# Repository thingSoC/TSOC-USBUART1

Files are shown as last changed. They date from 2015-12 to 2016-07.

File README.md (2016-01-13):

# TSOC-USBUART1

**TSOC-USBUART1** is a USB to UART Base Board **thingSoC Reference Design.** 

**thingSoC Reference Designs** are example thingSoC implementations that implement
various reference and testing circuits for demonstrating the use of the thingSoC libraries.
These reference designs can serve as starting templates for user designs.

**TSOC-USBUART1** includes a single channel USB to Serial(UART) interface, 
and status LED's, as well as an "FTDI" pinout compatible connector.

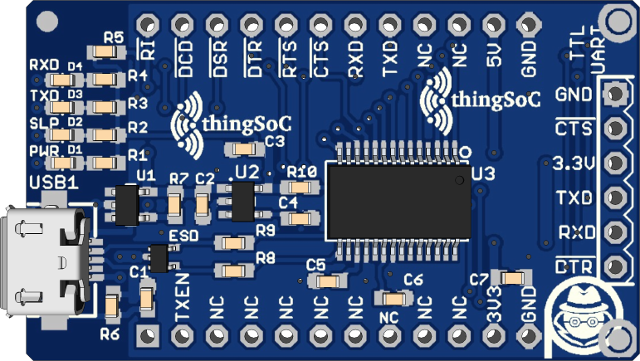
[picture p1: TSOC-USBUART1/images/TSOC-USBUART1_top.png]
thingSoC TSOC-USBUART1
[ 
*TSOC-USBUART1*](https://github.com/thingSoC/TSOC-USBUART1)

---------------------------------------

## TSOC-USBUART1 Status <a name="TSOC-USBUART1_status"/>

**01/13/2016:** 
Revision 3.1 - Revised USB ESD circuit to PA Standard USB2.0

**01/13/2016:** 
Revision 3.0 - NUF2221 ESD package pinout - PCB jumper with discrete resistors
Tested at 9600, 115200, 256000, 921600, 1843200 Baud rates

---------------------------------------

## TSOC-USBUART1 Documentation Index <a name="TSOC-USBUART1_documentation_index"/>

[TSOC-USBUART1 Project](http://thingsoc.github.io/projects/TSOC-USBUART1.html)

[TSOC-USBUART1 Hardware](https://github.com/thingSoC/TSOC-USBUART1/tree/master/TSOC-USBUART1/hardware)

---------------------------------------

## thingSoC Documentation Index <a name="thingSoC_documentation_index"/>

[thingSoC Organization Website](http://thingSoC.github.io)

[thingSoC FAQ - Frequently Asked Questions](http://thingsoc.github.io/support/faq.html)

---------------------------------------

[thingSoC 
*thingSoC*](http://thingsoc.github.io)

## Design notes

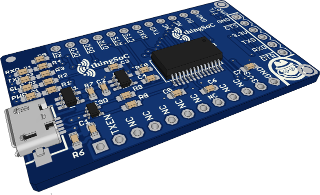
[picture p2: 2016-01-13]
TSOC-USBUART1/images/TSOC-USBUART1_model.png

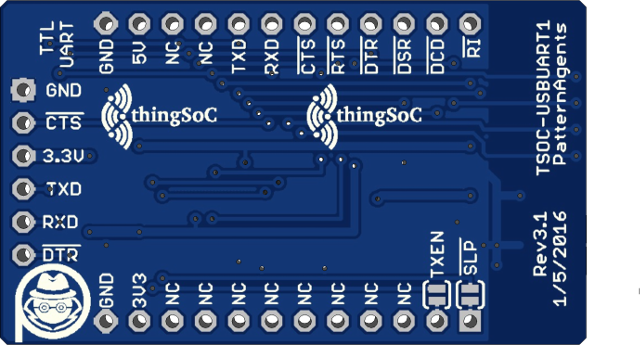
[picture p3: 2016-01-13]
TSOC-USBUART1/images/TSOC-USBUART1_bot.png

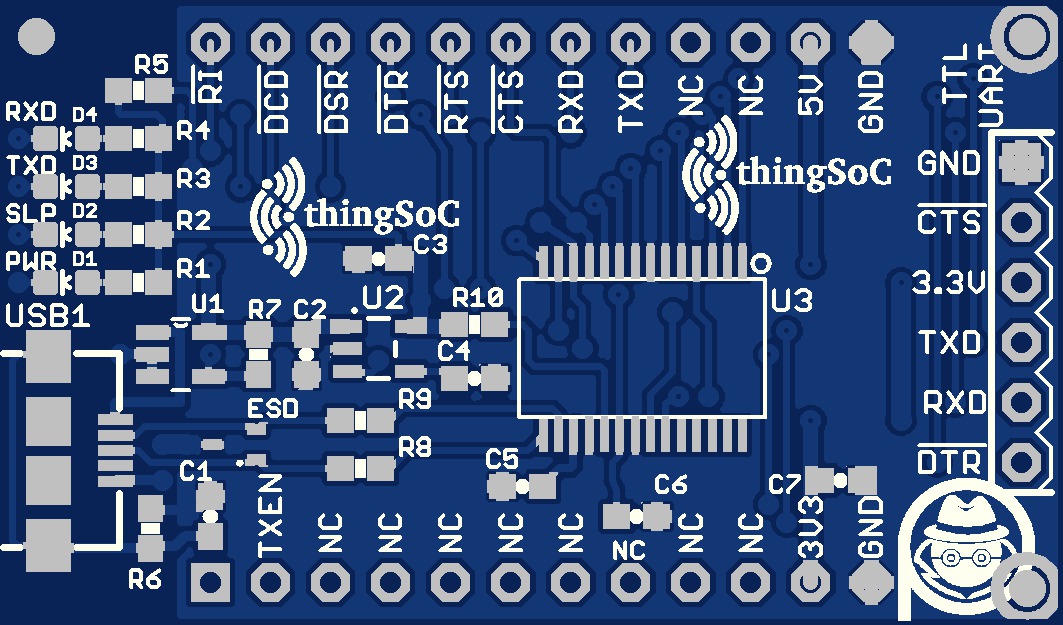
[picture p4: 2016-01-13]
TSOC-USBUART1/eagleUp/eagleUp_TSOC-USBUART1_board_top.jpg

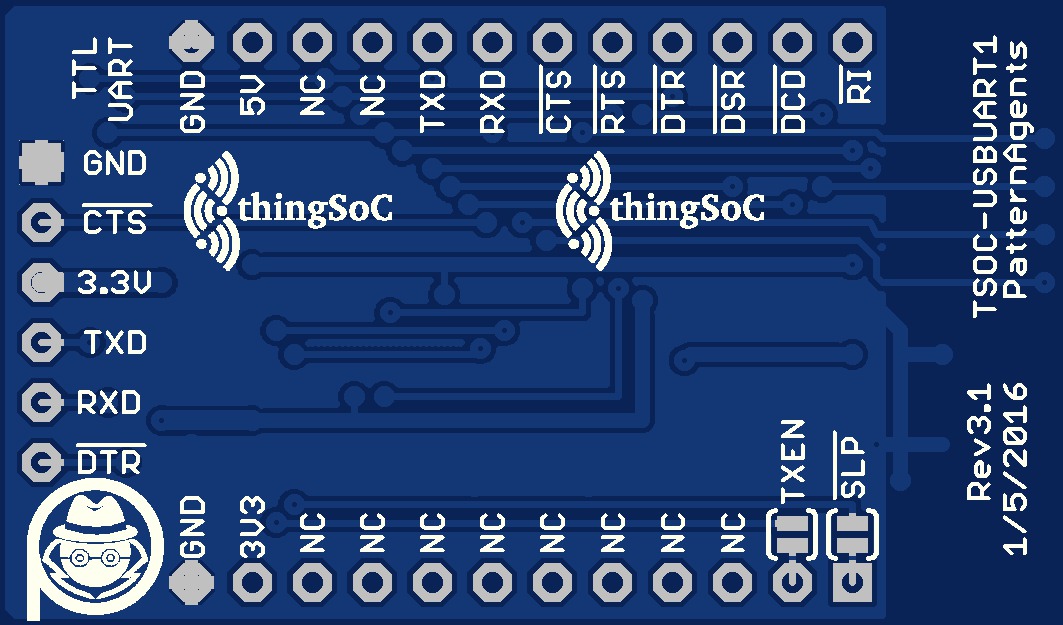
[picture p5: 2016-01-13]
TSOC-USBUART1/eagleUp/eagleUp_TSOC-USBUART1_board_bottom.jpg

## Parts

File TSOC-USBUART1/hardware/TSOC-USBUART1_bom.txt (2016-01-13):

/home/moxon/github/TSOC-USBUART1/TSOC-USBUART1/TSOC-USBUART1.sch (Revision 3.1)
----------------------------------------------------------------------------------------------
Qty Value               Device              Package               Parts            Description
----------------------------------------------------------------------------------------------
4   R/G/B/Y             LED0603             LED-0603              D1, D2, D3, D4   LEDs
2   0.1uF               CAP0603-CAP         0603-CAP              C6, C7           Capacitor
1   1.0uF               CAP0603-CAP         0603-CAP              C5               Capacitor
3   10K                 RESISTOR0603-RES    0603-RES              R5, R7, R10      Resistor
4   1K                  RESISTOR0603-RES    0603-RES              R1, R2, R3, R4   Resistor
1   1M                  RESISTOR0603-RES    0603-RES              R6               Resistor
2   2.2uF               CAP0603-CAP         0603-CAP              C2, C3           Capacitor
2   22                  RESISTOR0603-RES    0603-RES              R8, R9           Resistor
2   470pF               CAP0603-CAP         0603-CAP              C1, C4           Capacitor
1   CY7C65213-28PVXI    CY7C65213-28PVXI    SSOP28DB              U3               CY7C65213-28PVXI
1   MIC5219 3.3V        V_REG_MIC52193.3V   SOT23-5               U2               V_REG MIC5219
1   NCP361SNT1G         NCP361SNT1G         SOP95P275X110-5N      U1               USB Overvoltage Protection
1   PA_FTDI_BASIC_HOST- PA_FTDI_BASIC_HOST- PA_FTDI_M6X1          UART             6 Pin Female RA 0.1"
1   SP1001-02JTG        SP1001-02JTG        SC70-3                ESD              TVS Diode Array
1   USB_AB              USB_AB              USB-AB-MICRO-SMD      USB1             USB AB

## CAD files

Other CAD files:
TSOC-USBUART1/eagleUp/TSOC-USBUART1.skp

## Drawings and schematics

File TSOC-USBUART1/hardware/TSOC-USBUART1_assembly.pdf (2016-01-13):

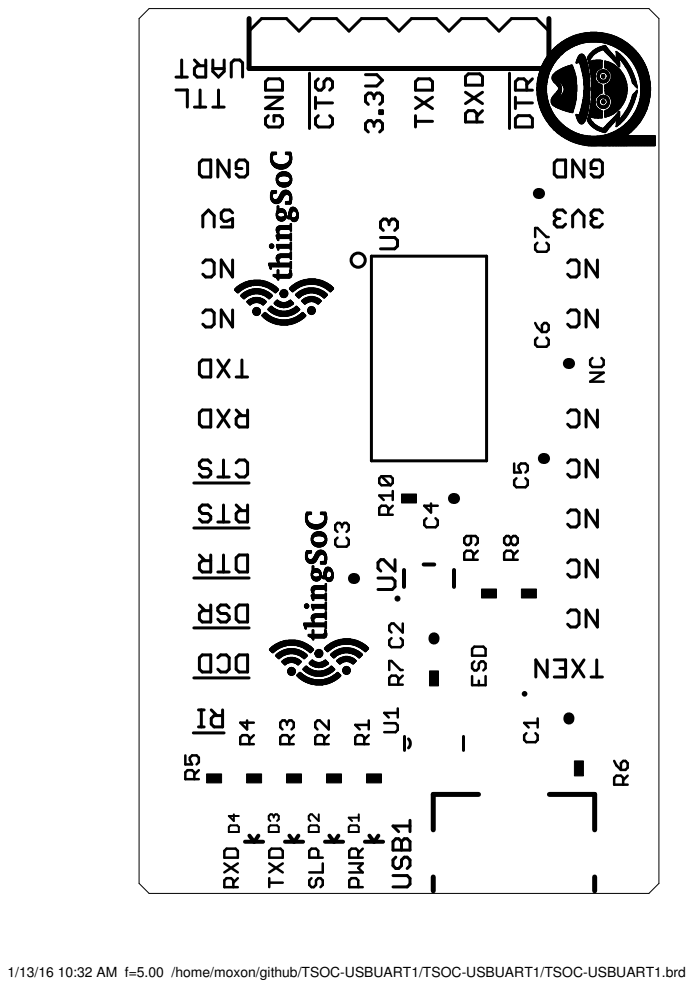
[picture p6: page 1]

1/13/16 10:32 AM f=5.00 /home/moxon/github/TSOC-USBUART1/TSOC-USBUART1/TSOC-USBUART1.brd

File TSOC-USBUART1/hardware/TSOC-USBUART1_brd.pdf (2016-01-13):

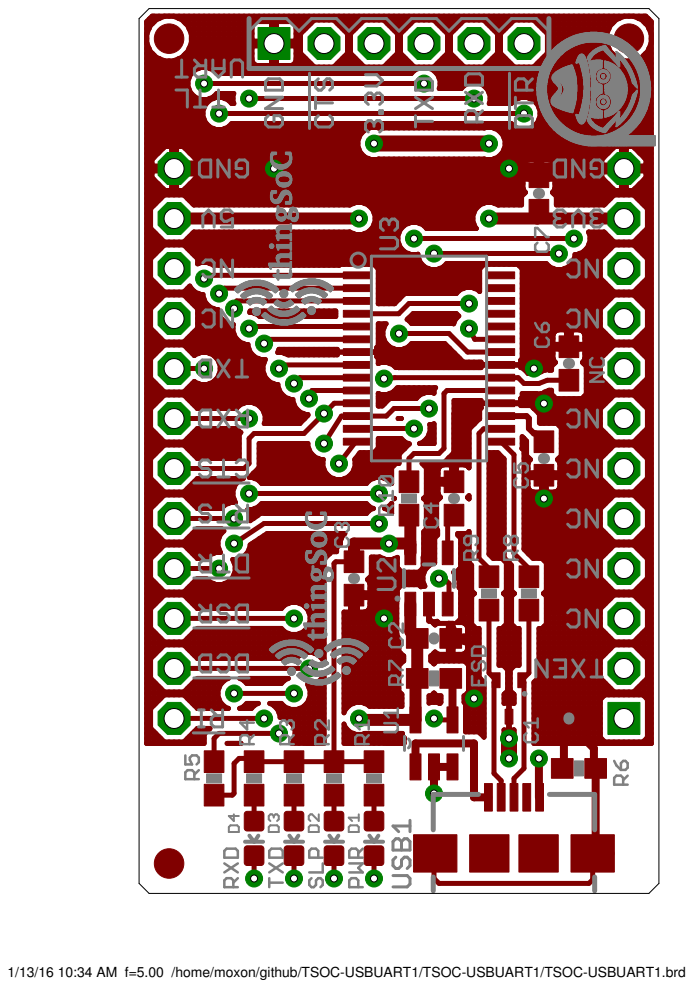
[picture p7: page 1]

1/13/16 10:34 AM f=5.00 /home/moxon/github/TSOC-USBUART1/TSOC-USBUART1/TSOC-USBUART1.brd

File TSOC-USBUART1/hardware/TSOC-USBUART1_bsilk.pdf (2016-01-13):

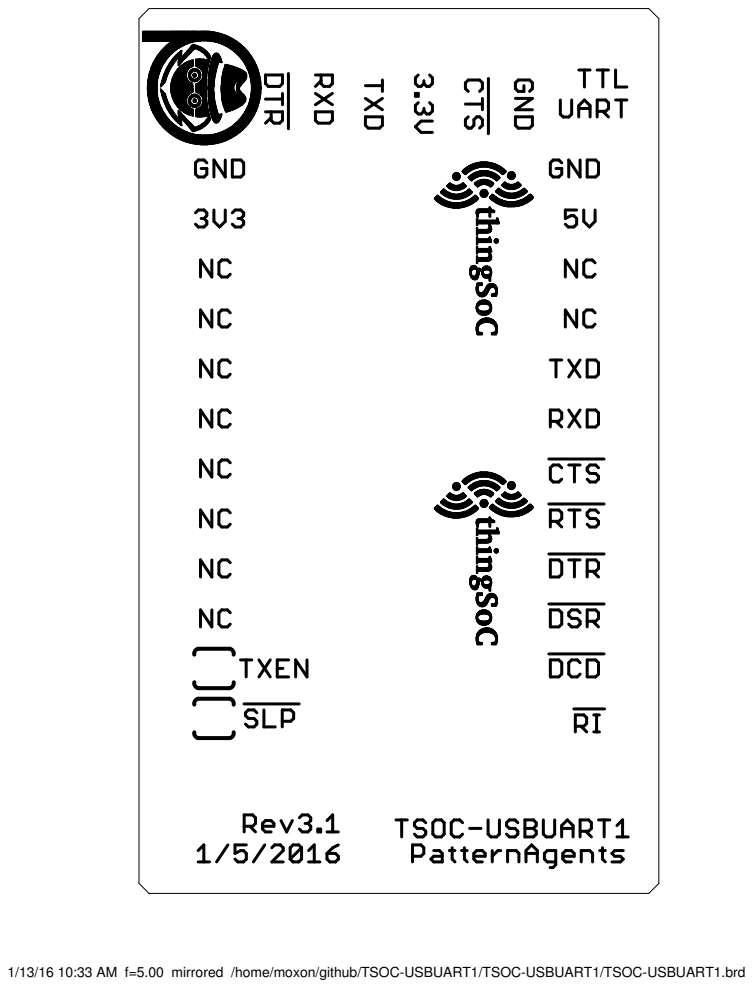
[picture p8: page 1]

1/13/16 10:33 AM f=5.00 mirrored /home/moxon/github/TSOC-USBUART1/TSOC-USBUART1/TSOC-USBUART1.brd

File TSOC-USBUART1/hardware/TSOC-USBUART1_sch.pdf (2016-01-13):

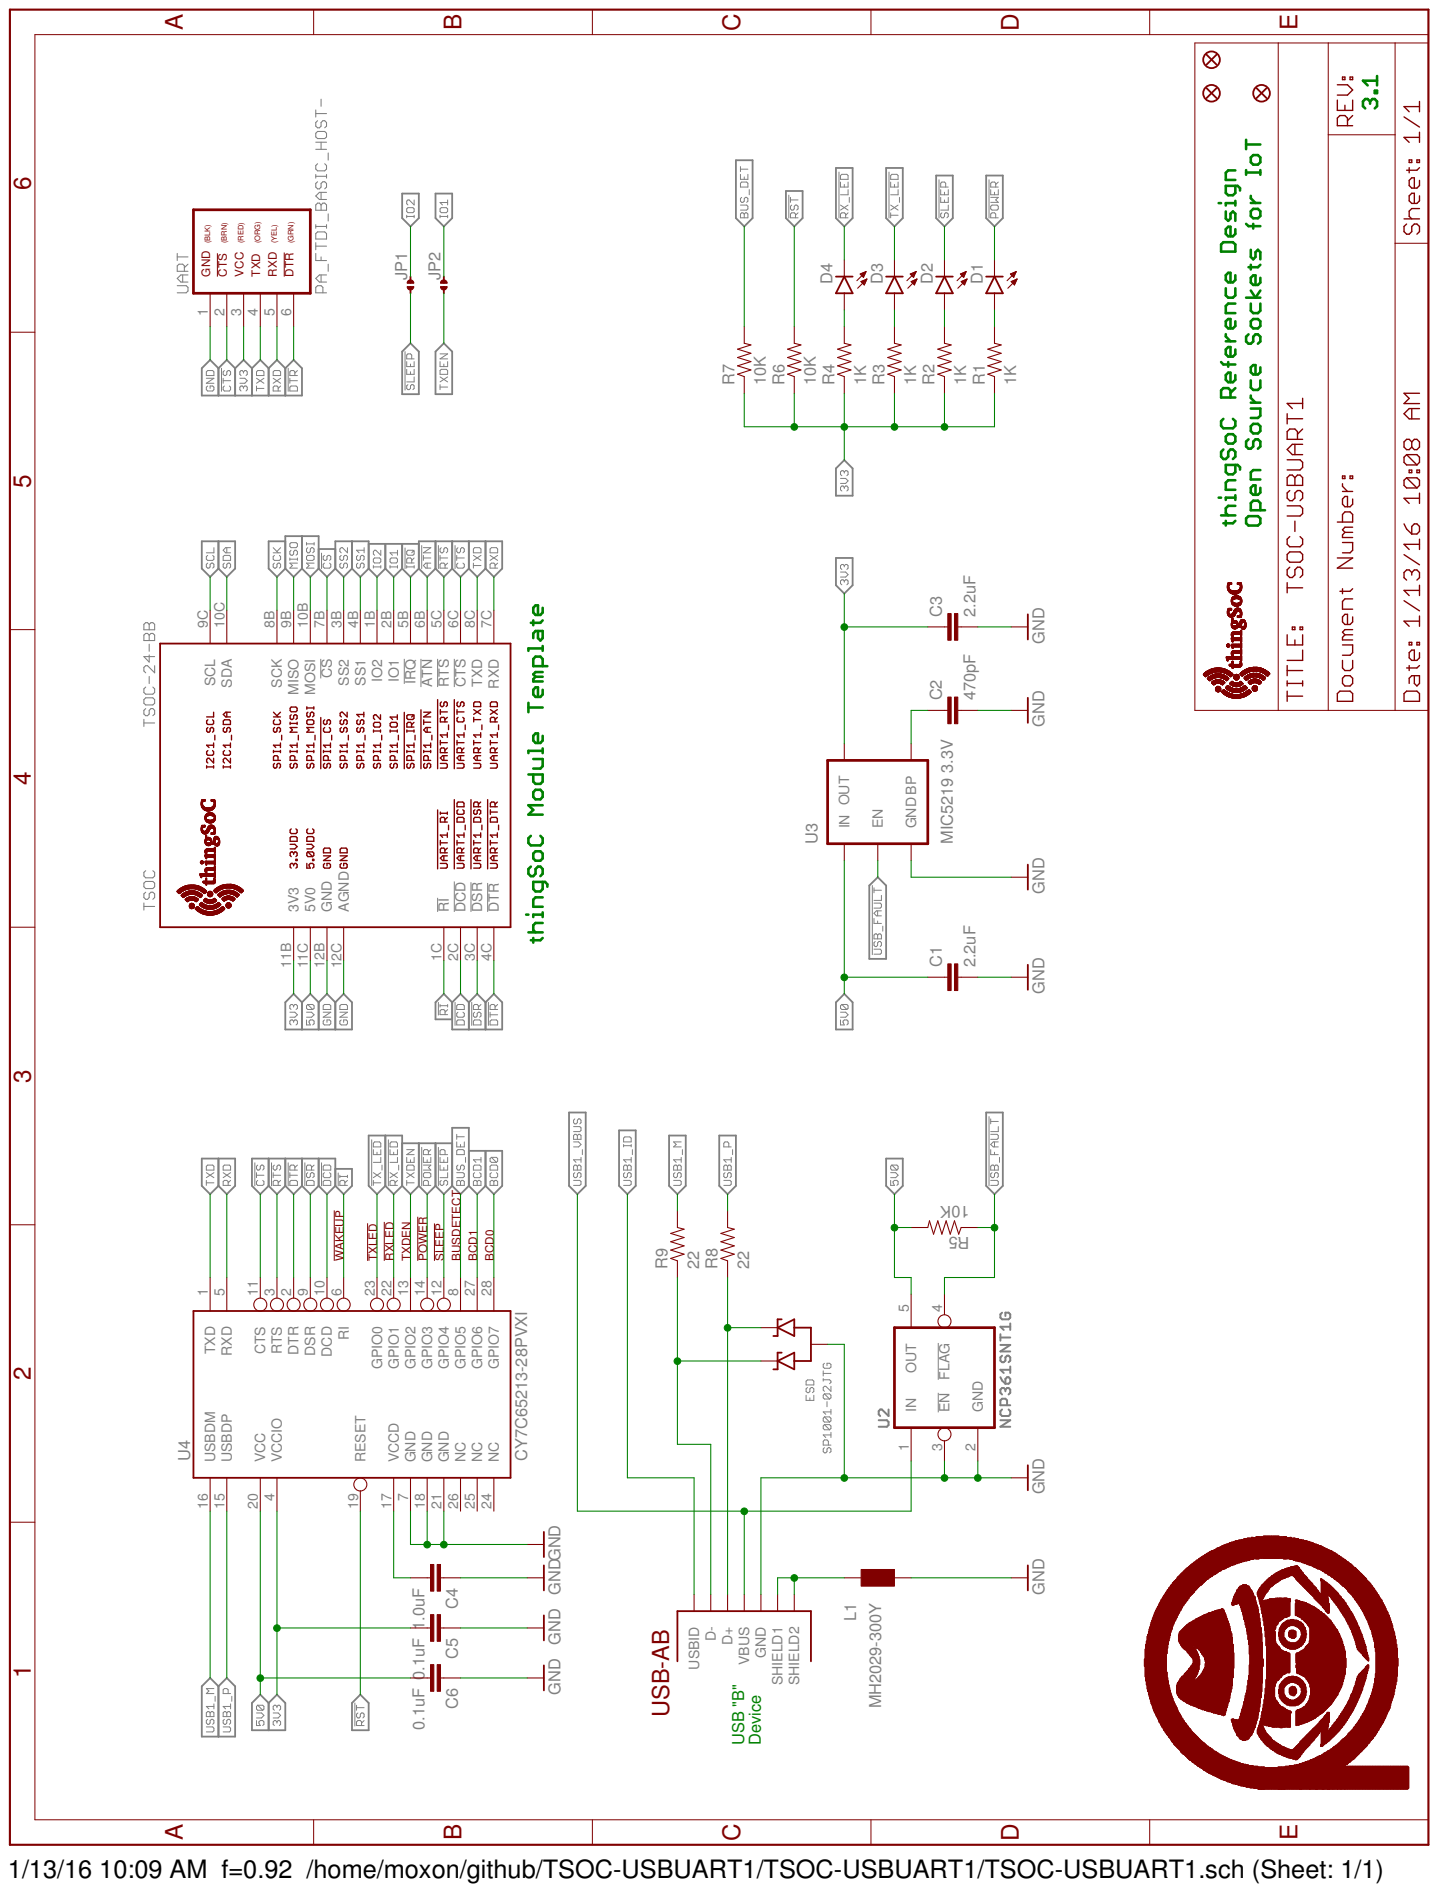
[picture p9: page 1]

1/13/16 10:09 AM f=0.92 /home/moxon/github/TSOC-USBUART1/TSOC-USBUART1/TSOC-USBUART1.sch (Sheet: 1/1)

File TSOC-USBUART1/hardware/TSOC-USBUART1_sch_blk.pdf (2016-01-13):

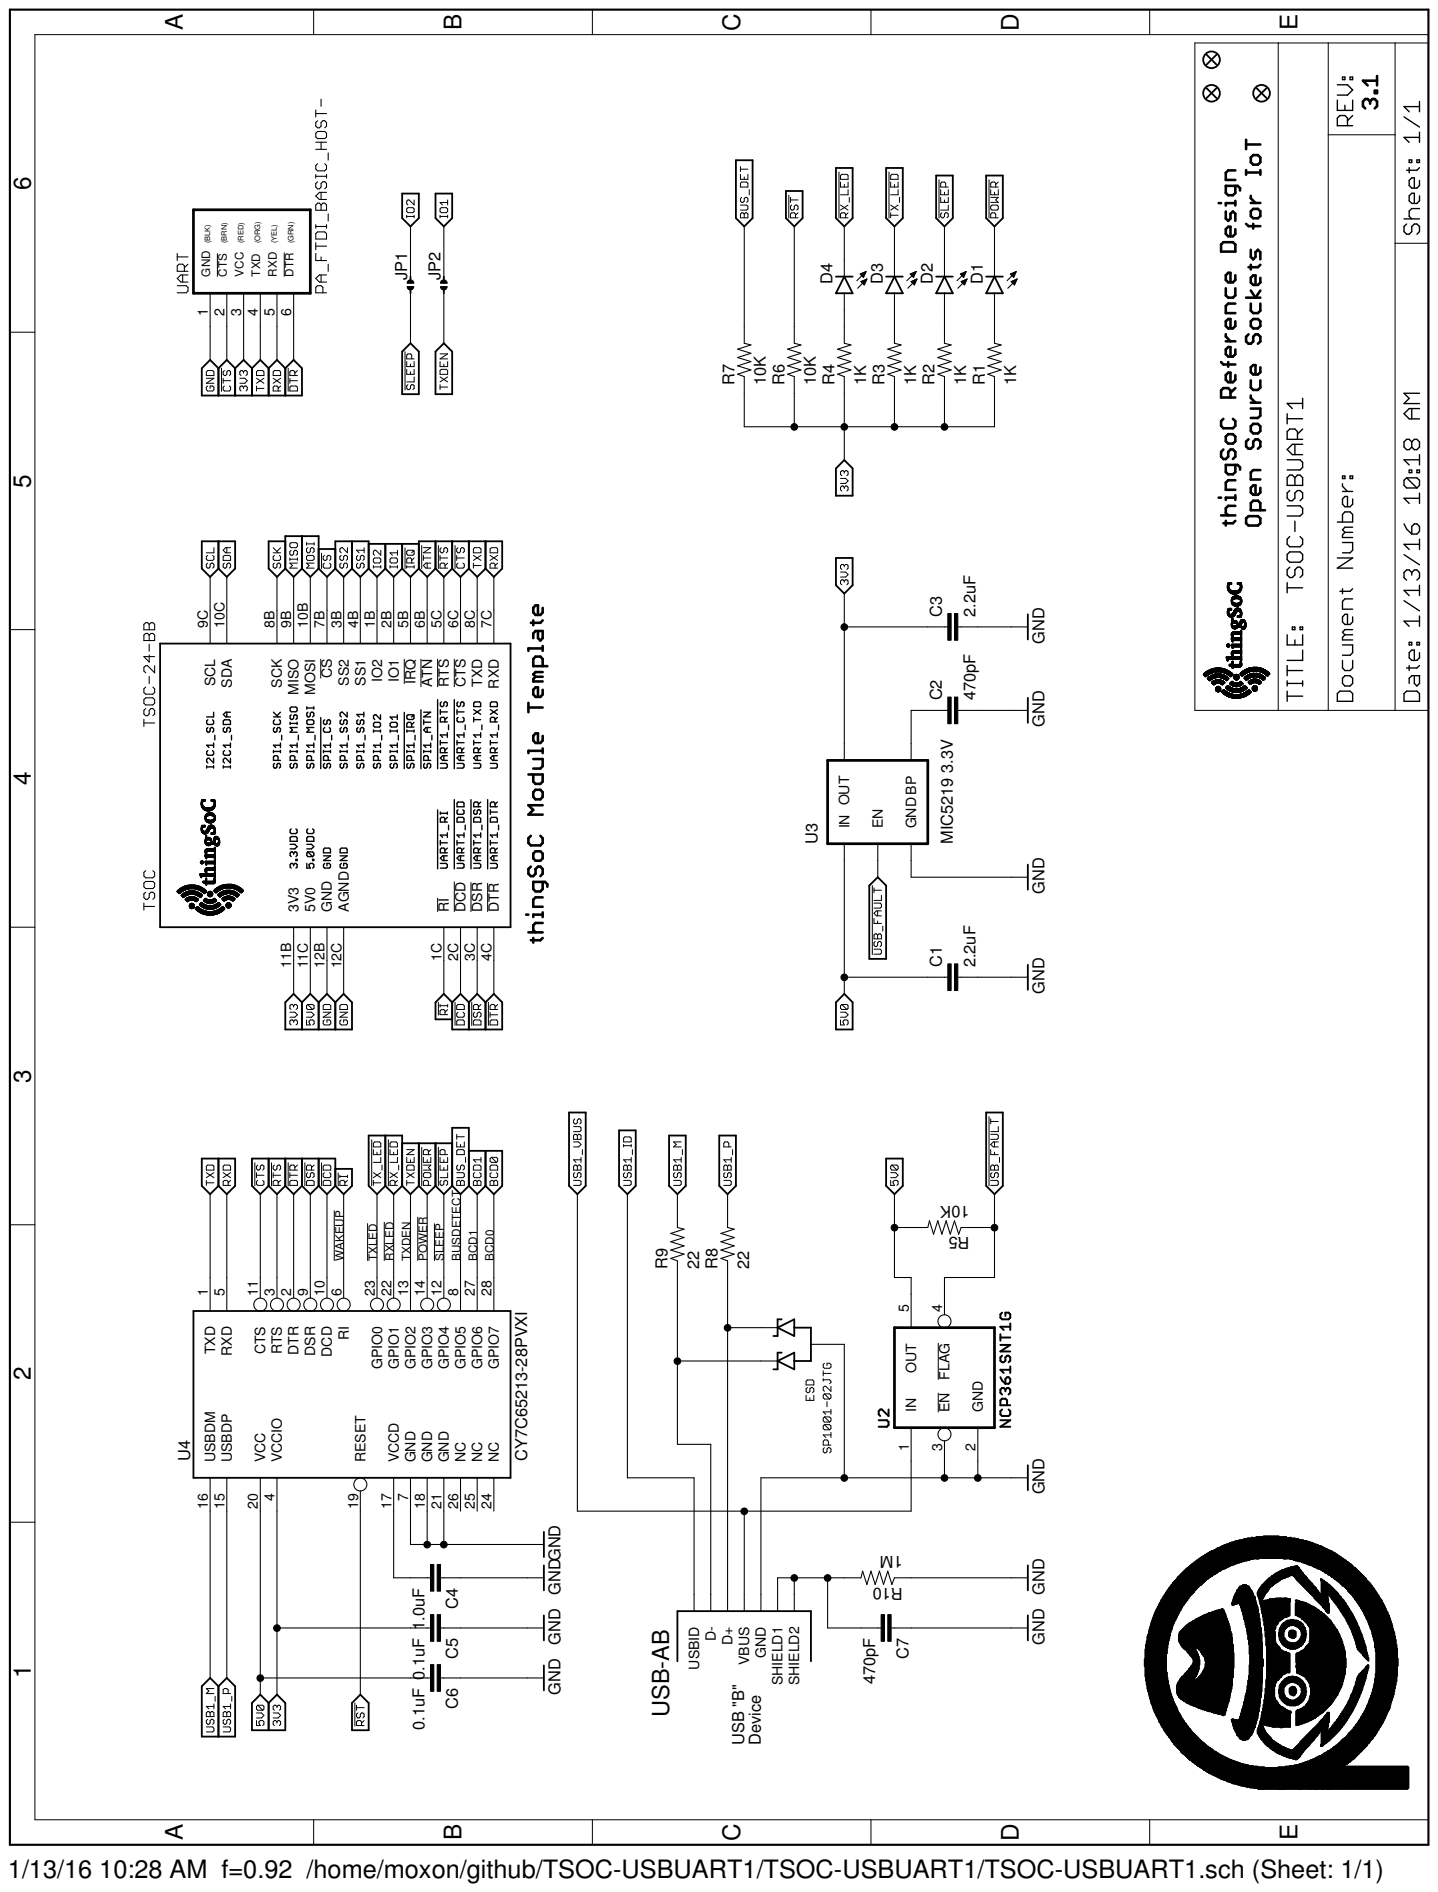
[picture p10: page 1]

1/13/16 10:28 AM f=0.92 /home/moxon/github/TSOC-USBUART1/TSOC-USBUART1/TSOC-USBUART1.sch (Sheet: 1/1)

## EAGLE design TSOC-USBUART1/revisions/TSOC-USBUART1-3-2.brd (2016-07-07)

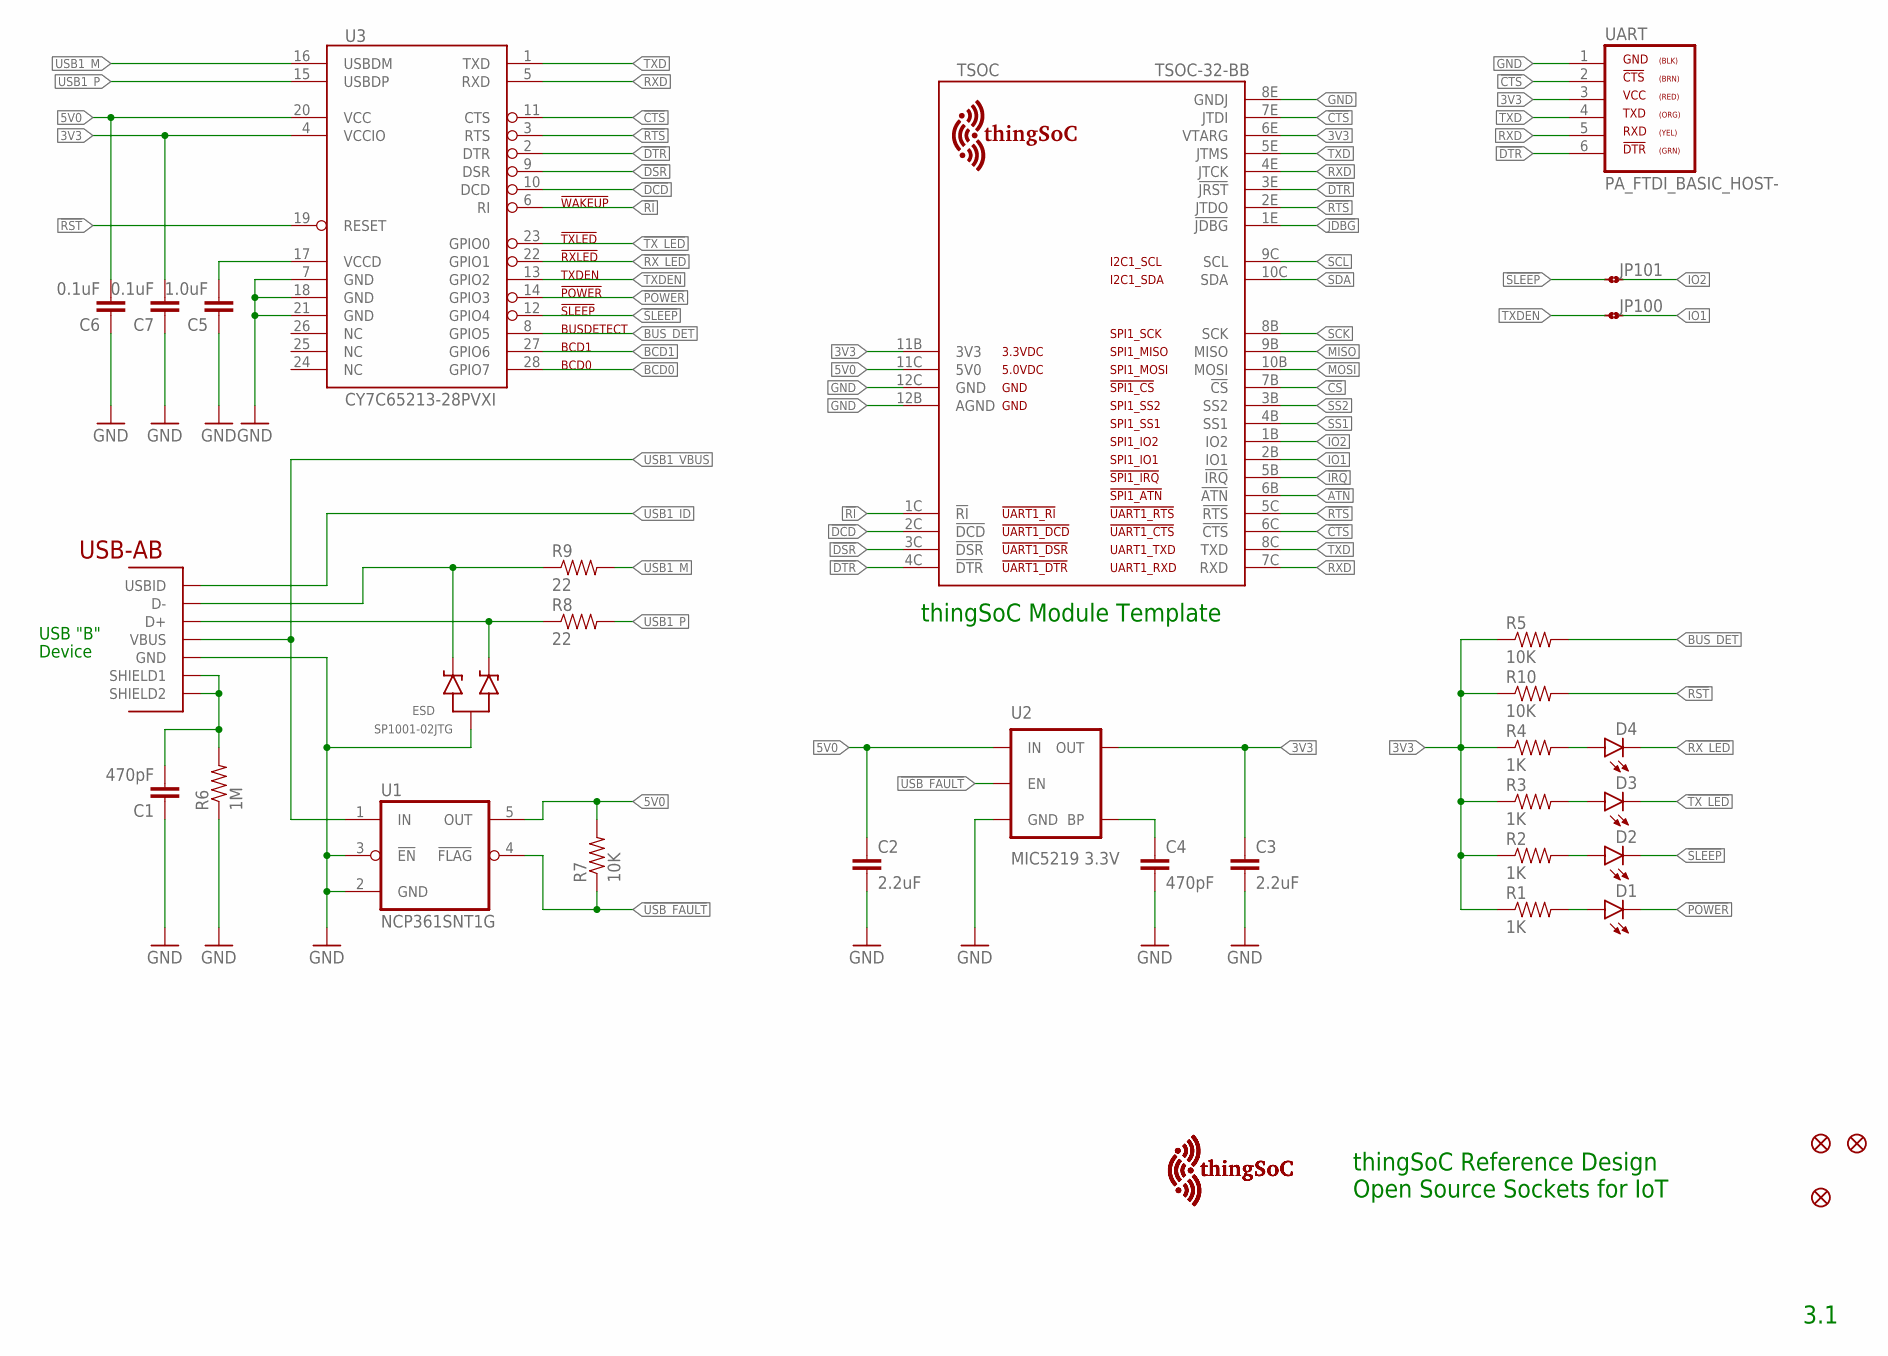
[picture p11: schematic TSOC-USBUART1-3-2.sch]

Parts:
C1, C4: 470pF; 0603-CAP
C2, C3: 2.2uF; 0603-CAP
C5: 1.0uF; 0603-CAP
C6, C7: 0.1uF; 0603-CAP
D1, D2, D3, D4: LED0603; LED-0603
ESD: SP1001-02JTG; SC70-3
FID1, FID2, FID3: FIDUCIAL1.5X3; FIDUCIAL-1.5X3
JP100, JP101: JMP-2-NO
R1, R2, R3, R4: 1K; 0603-RES
R5, R7, R10: 10K; 0603-RES
R6: 1M; 0603-RES
R8, R9: 22; 0603-RES
TSOC: TSOC-32-BB; TSOC-BB-S32
U1: NCP361SNT1G; SOP95P275X110-5N
U2: MIC5219 3.3V; SOT23-5
U3: CY7C65213-28PVXI; SSOP28DB
U$2, U$101: TSOC-LOGO-MED
UART: PA_FTDI_BASIC_HOST-; PA_FTDI_M5X1
USB1: USB_AB; USB-AB-MICRO-SMD

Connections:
3V3: C3.1, C7.2, R1.1, R2.1, R3.1, R4.1, R5.1, R10.1, TSOC.6E (VTARG), TSOC.11B (3V3), U2.5 (OUT), U3.4 (VCCIO), UART.3
5V0: C2.1, C6.2, R7.2, TSOC.11C (5V0), U1.5 (OUT), U2.1 (IN), U3.20 (VCC)
!ATN: TSOC.6B (!ATN)
!CS: TSOC.7B (!CS)
!CTS: TSOC.6C (!CTS), TSOC.7E (JTDI), U3.11 (CTS), UART.2
!DCD: TSOC.2C (!DCD), U3.10 (DCD)
!DSR: TSOC.3C (!DSR), U3.9 (DSR)
!DTR: TSOC.3E (!JRST), TSOC.4C (!DTR), U3.2 (DTR), UART.6
!IRQ: TSOC.5B (!IRQ)
!JDBG: TSOC.1E (!JDBG)
!POWER: D1.C, U3.14 (GPIO3)
!RI: TSOC.1C (!RI), U3.6 (RI)
!RST: R10.2, U3.19 (RESET)
!RTS: TSOC.2E (JTDO), TSOC.5C (!RTS), U3.3 (RTS)
!RX_LED: D4.C, U3.22 (GPIO1)
!SLEEP: D2.C, JP101.1, U3.12 (GPIO4)
!TX_LED: D3.C, U3.23 (GPIO0)
!USB_FAULT: R7.1, U1.4 (!FLAG), U2.3 (EN)
BCD0: U3.28 (GPIO7)
BCD1: U3.27 (GPIO6)
BLUE: D3.A, R3.2
BUS_DET: R5.2, U3.8 (GPIO5)
BYPASS: C4.1, U2.4 (BP)
GND: C1.1, C2.2, C3.2, C4.2, C5.1, C6.1, C7.1, ESD.3 (A), R6.1, TSOC.8E (GNDJ), TSOC.12B (AGND), TSOC.12C (GND), U1.2 (GND), U1.3 (!EN), U2.2 (GND), U3.7 (GND), U3.18 (GND), U3.21 (GND), UART.1, USB1.GND
GRN: D1.A, R1.2
IO1: JP100.2, TSOC.2B (IO1)
IO2: JP101.2, TSOC.1B (IO2)
MISO: TSOC.9B (MISO)
MOSI: TSOC.10B (MOSI)
RED: D2.A, R2.2
RXD: TSOC.4E (JTCK), TSOC.7C (RXD), U3.5 (RXD), UART.5
SCK: TSOC.8B (SCK)
SCL: TSOC.9C (SCL)
SDA: TSOC.10C (SDA)
SS1: TSOC.4B (SS1)
SS2: TSOC.3B (SS2)
TXD: TSOC.5E (JTMS), TSOC.8C (TXD), U3.1 (TXD), UART.4
TXDEN: JP100.1, U3.13 (GPIO2)
USB1_DM: ESD.2 (C2), R9.1, USB1.D-
USB1_DP: ESD.1 (C1), R8.1, USB1.D+
USB1_ID: USB1.ID (USBID)
USB1_M: R9.2, U3.16 (USBDM)
USB1_P: R8.2, U3.15 (USBDP)
USB1_SHIELD: C1.2, R6.2, USB1.SHIELD1, USB1.SHIELD2
USB1_VBUS: U1.1 (IN), USB1.VBUS
VCCD: C5.2, U3.17 (VCCD)
YEL: D4.A, R4.2

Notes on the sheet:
thingSoC Module Template
USB "B"
Device
thingSoC Reference Design Open Source Sockets for IoT
3.1

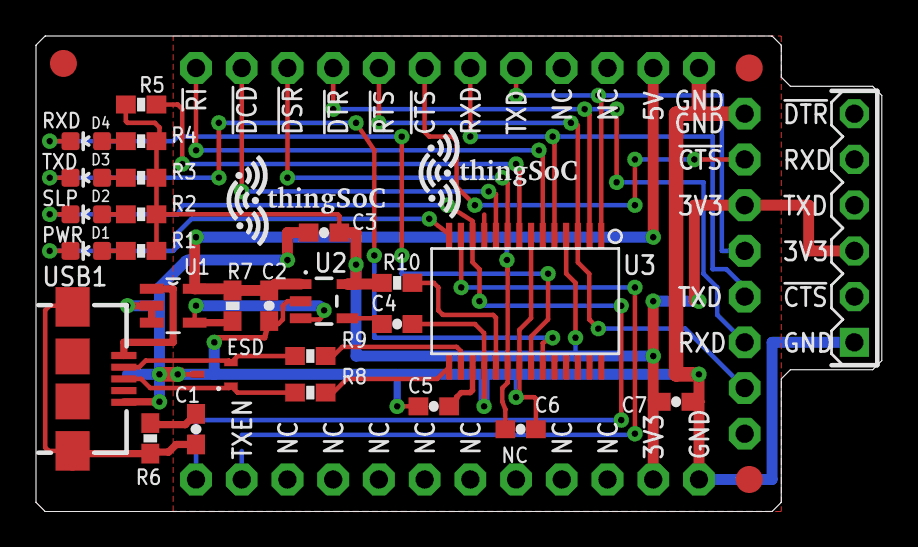
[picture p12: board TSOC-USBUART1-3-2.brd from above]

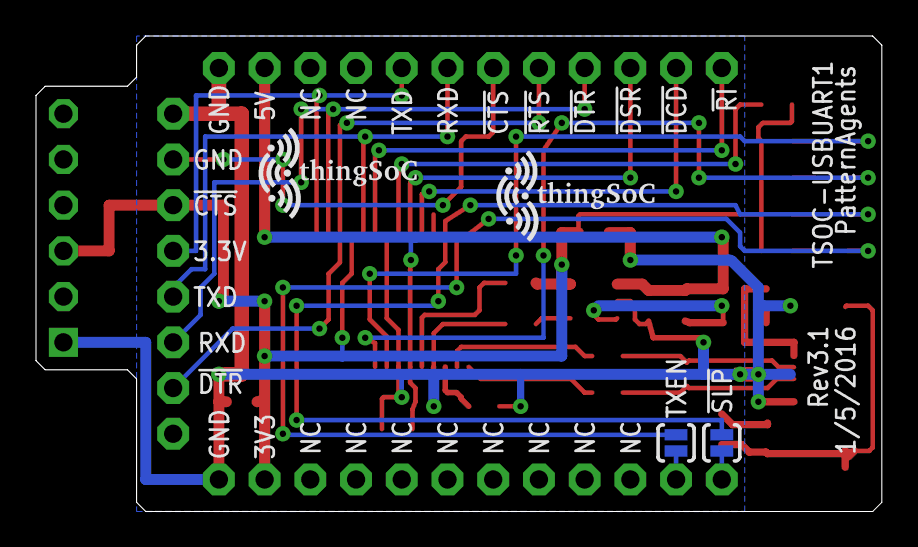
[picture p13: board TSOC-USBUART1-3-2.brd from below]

Board: 2 copper layers, 47.0 x 26.4 mm, 37 parts (4 on the bottom side), 33 nets.

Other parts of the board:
U$1, U$102: TSOC-LOGO-MED

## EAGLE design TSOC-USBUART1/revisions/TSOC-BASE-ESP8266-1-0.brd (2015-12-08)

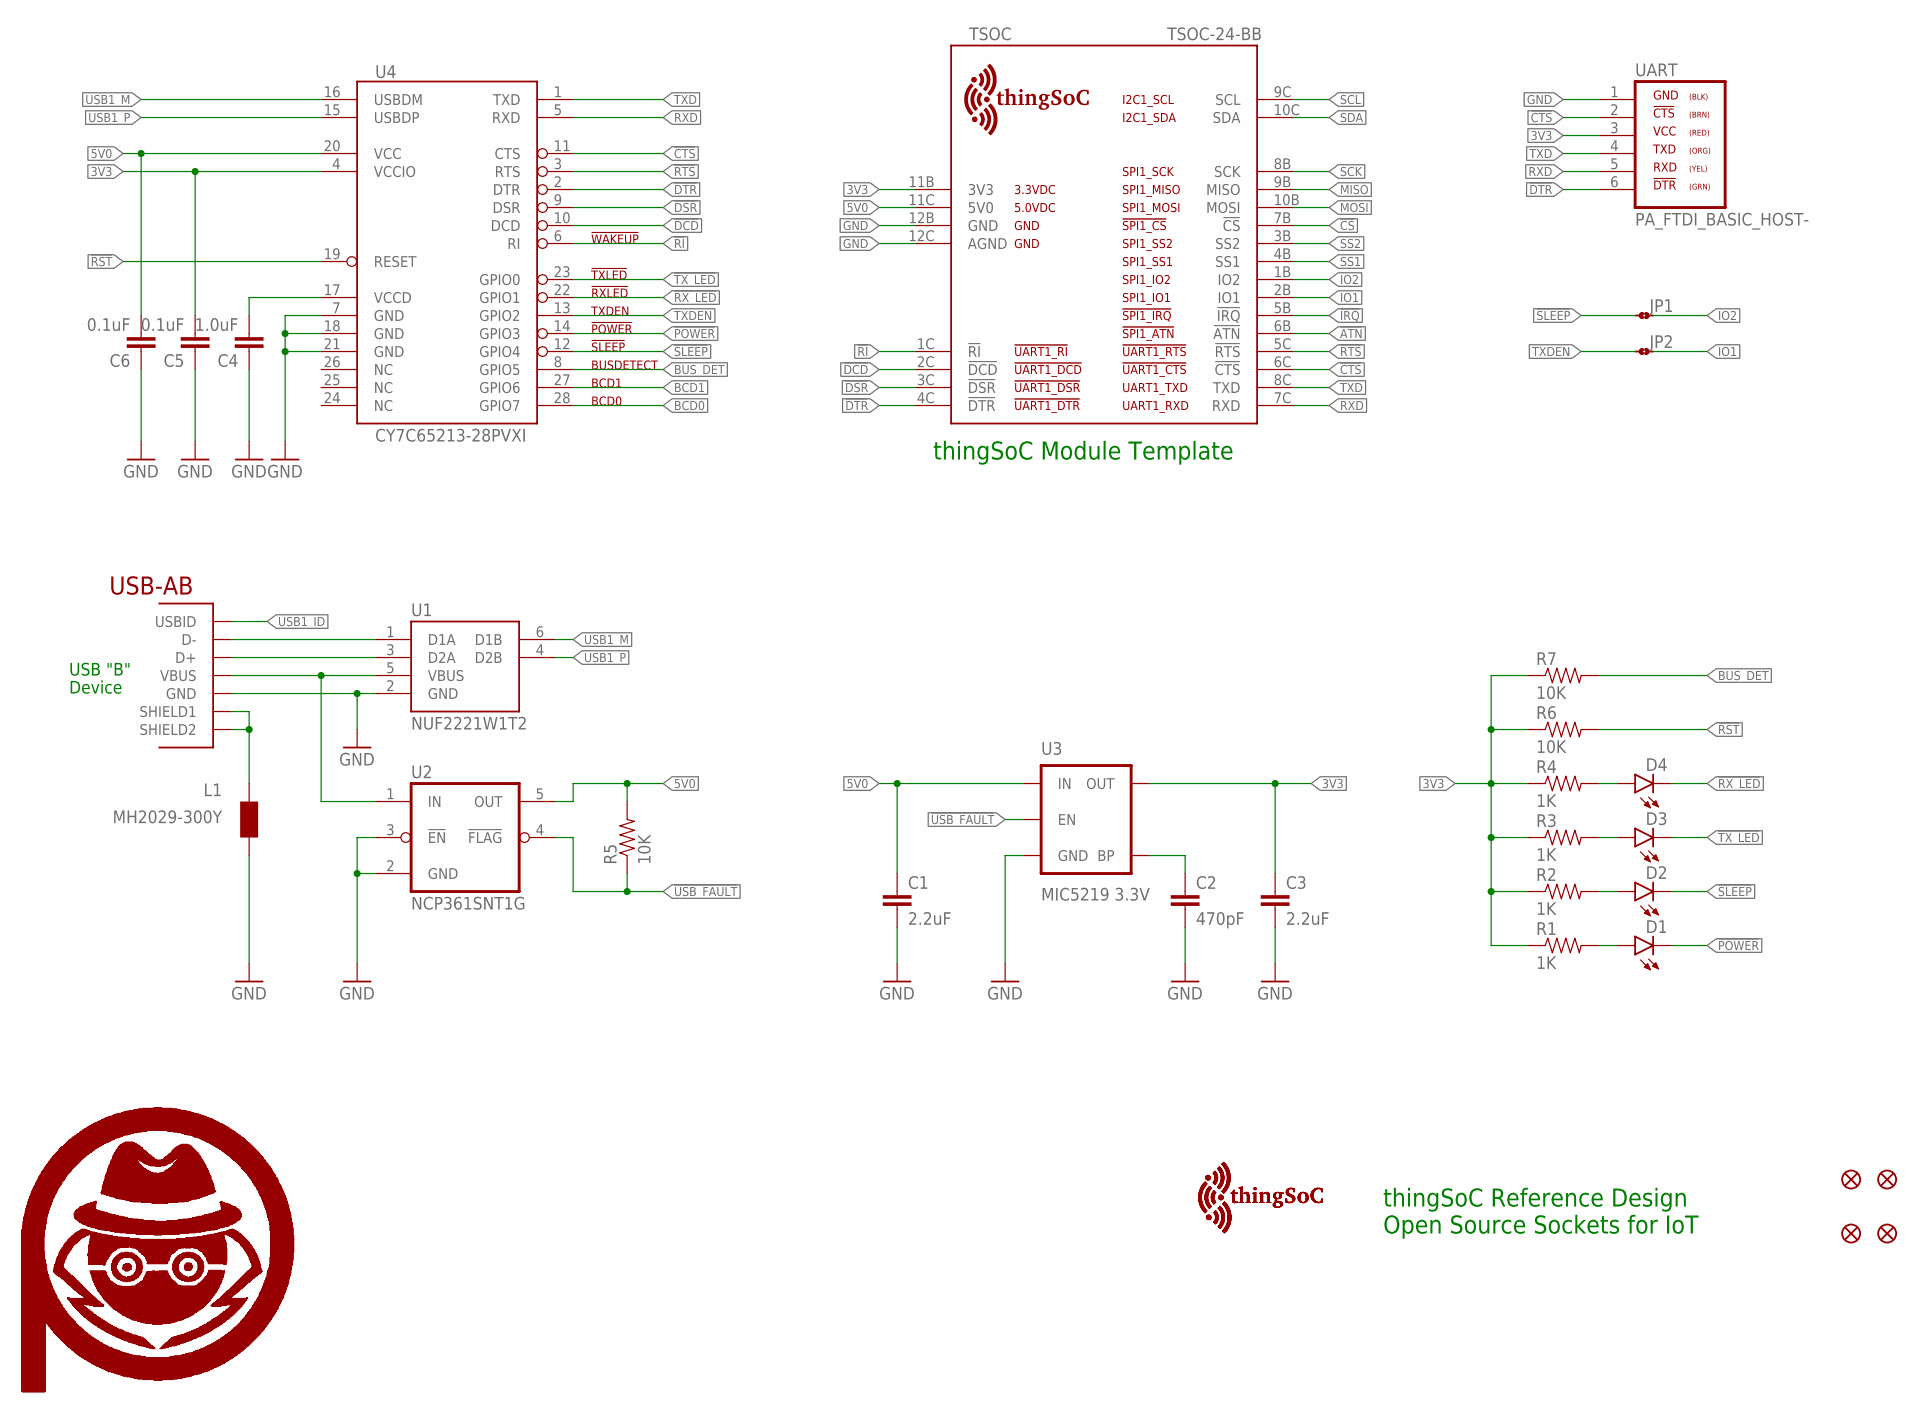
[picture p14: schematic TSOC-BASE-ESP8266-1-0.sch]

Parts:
C1, C3: 2.2uF; 0603-CAP
C2: 470pF; 0603-CAP
C4: 1.0uF; 0603-CAP
C5, C6: 0.1uF; 0603-CAP
D1, D2, D3, D4: LED0603; LED-0603
FID1, FID2, FID3, FID4: FIDUCIAL1.5X3; FIDUCIAL-1.5X3
JP1, JP2: JMP-2-NO
L1: MH2029-300Y; 0805
R1, R2, R3, R4: 1K; 0603-RES
R5, R6, R7: 10K; 0603-RES
TSOC: TSOC-24-BB; TSOC-BB-S24
U1: NUF2221W1T2; SOT-363
U2: NCP361SNT1G; SOP95P275X110-5N
U3: MIC5219 3.3V; SOT23-5
U4: CY7C65213-28PVXI; SSOP28DB
U$1, U$2: PA_LOGO_SYMMED; PA_LOGO_AGENT_MED_SYM
U$3, U$4: TSOC-LOGO-SMALL; TSOC-LOGO-SML
UART: PA_FTDI_BASIC_HOST-; PA_FTDI_M5X1
USB1: USB_AB; USB-AB-MICRO-SMD

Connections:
3V3: C3.1, C5.2, R1.1, R2.1, R3.1, R4.1, R6.1, R7.1, TSOC.11B (3V3), U3.5 (OUT), U4.4 (VCCIO), UART.3
5V0: C1.1, C6.2, R5.2, TSOC.11C (5V0), U2.5 (OUT), U3.1 (IN), U4.20 (VCC)
!ATN: TSOC.6B (!ATN)
!CS: TSOC.7B (!CS)
!CTS: TSOC.6C (!CTS), U4.11 (CTS), UART.2
!DCD: TSOC.2C (!DCD), U4.10 (DCD)
!DSR: TSOC.3C (!DSR), U4.9 (DSR)
!DTR: TSOC.4C (!DTR), U4.2 (DTR), UART.6
!IRQ: TSOC.5B (!IRQ)
!POWER: D1.C, U4.14 (GPIO3)
!RI: TSOC.1C (!RI), U4.6 (RI)
!RST: R6.2, U4.19 (RESET)
!RTS: TSOC.5C (!RTS), U4.3 (RTS)
!RX_LED: D4.C, U4.22 (GPIO1)
!SLEEP: D2.C, JP1.1, U4.12 (GPIO4)
!TX_LED: D3.C, U4.23 (GPIO0)
!USB_FAULT: R5.1, U2.4 (!FLAG), U3.3 (EN)
BCD0: U4.28 (GPIO7)
BCD1: U4.27 (GPIO6)
BLUE: D3.A, R3.2
BUS_DET: R7.2, U4.8 (GPIO5)
BYPASS: C2.1, U3.4 (BP)
GND: C1.2, C2.2, C3.2, C4.1, C5.1, C6.1, L1.2, TSOC.12B (GND), TSOC.12C (AGND), U1.2 (GND), U2.2 (GND), U2.3 (!EN), U3.2 (GND), U4.7 (GND), U4.18 (GND), U4.21 (GND), UART.1, USB1.GND
GRN: D1.A, R1.2
IO1: JP2.2, TSOC.2B (IO1)
IO2: JP1.2, TSOC.1B (IO2)
MISO: TSOC.9B (MISO)
MOSI: TSOC.10B (MOSI)
RED: D2.A, R2.2
RXD: TSOC.7C (RXD), U4.5 (RXD), UART.5
SCK: TSOC.8B (SCK)
SCL: TSOC.9C (SCL)
SDA: TSOC.10C (SDA)
SS1: TSOC.4B (SS1)
SS2: TSOC.3B (SS2)
TXD: TSOC.8C (TXD), U4.1 (TXD), UART.4
TXDEN: JP2.1, U4.13 (GPIO2)
USB1_DM: U1.1 (D1A), USB1.D-
USB1_DP: U1.3 (D2A), USB1.D+
USB1_ID: USB1.ID (USBID)
USB1_M: U1.6 (D1B), U4.16 (USBDM)
USB1_P: U1.4 (D2B), U4.15 (USBDP)
USB1_SHIELD: L1.1, USB1.SHIELD1, USB1.SHIELD2
USB1_VBUS: U1.5 (VBUS), U2.1 (IN), USB1.VBUS
VCCD: C4.2, U4.17 (VCCD)
YEL: D4.A, R4.2

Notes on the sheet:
thingSoC Module Template
USB "B"
Device
thingSoC Reference Design Open Source Sockets for IoT

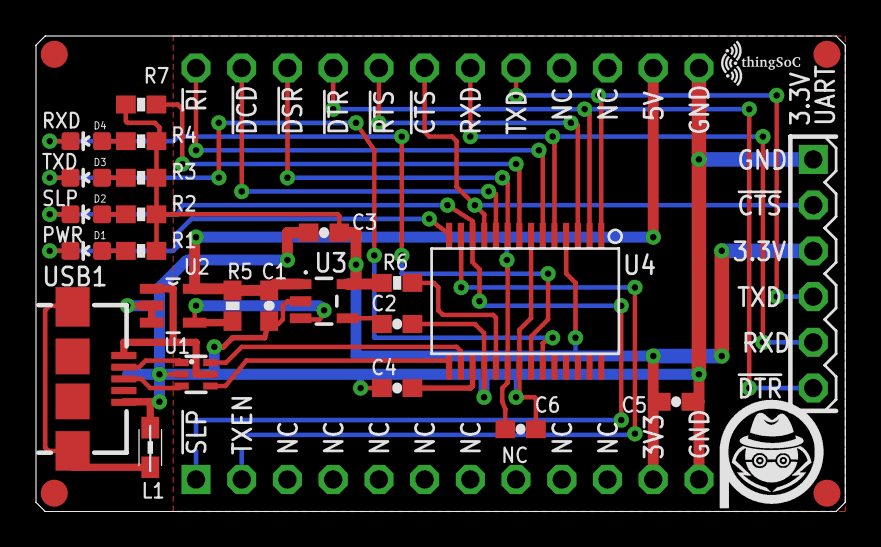
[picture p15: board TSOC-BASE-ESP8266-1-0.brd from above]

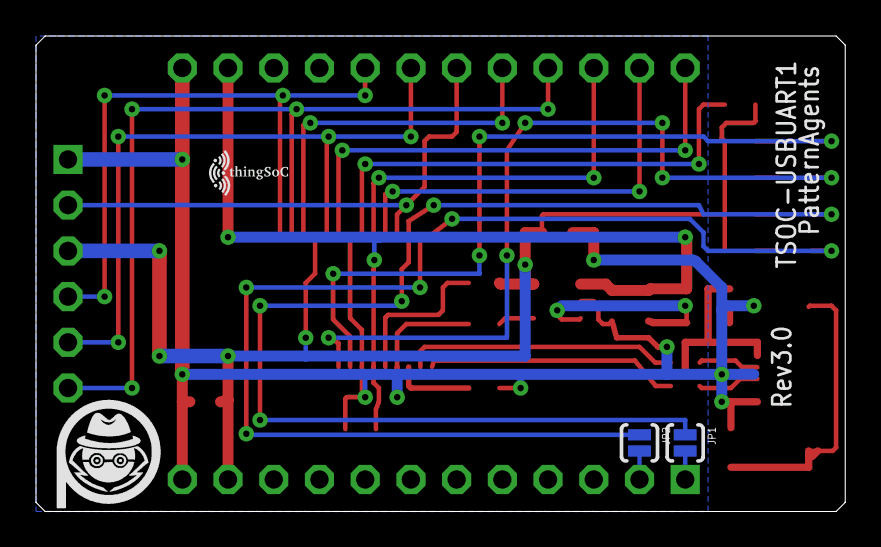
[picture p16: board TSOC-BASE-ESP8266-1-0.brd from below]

Board: 2 copper layers, 45.0 x 26.4 mm, 35 parts (4 on the bottom side), 33 nets.

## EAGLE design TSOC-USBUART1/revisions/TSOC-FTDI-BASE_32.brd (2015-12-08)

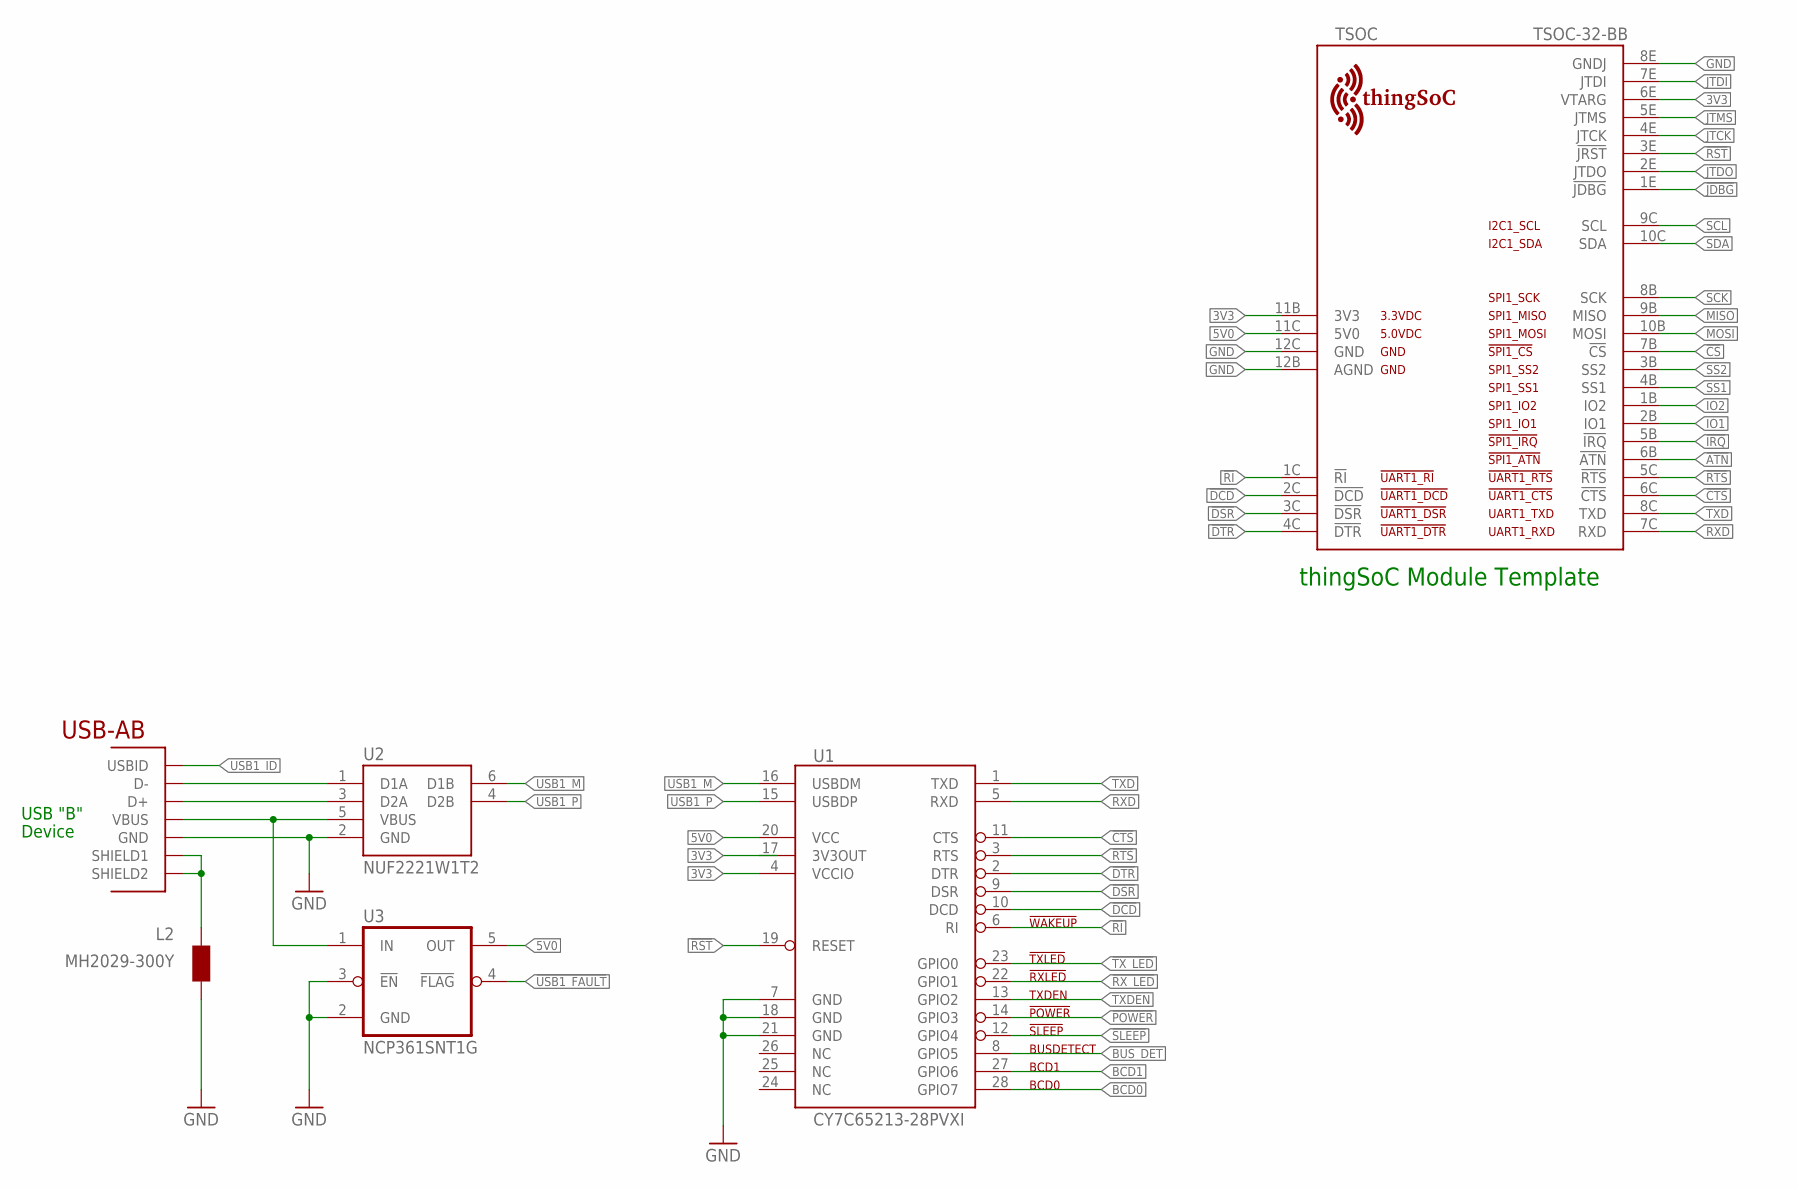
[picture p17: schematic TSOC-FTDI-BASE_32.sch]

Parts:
L2: MH2029-300Y; 0805
TSOC: TSOC-32-BB; TSOC-BB-S32
U1: CY7C65213-28PVXI; SSOP28DB
U2: NUF2221W1T2; SOT-363
U3: NCP361SNT1G; SOP95P275X110-5N
USB1: USB_AB; USB-AB-MICRO-SMD

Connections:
3V3: TSOC.6E (VTARG), TSOC.11B (3V3), U1.4 (VCCIO)
5V0: TSOC.11C (5V0), U1.20 (VCC), U3.5 (OUT)
!ATN: TSOC.6B (!ATN)
!CS: TSOC.7B (!CS)
!CTS: TSOC.6C (!CTS), U1.11 (CTS)
!DCD: TSOC.2C (!DCD), U1.10 (DCD)
!DSR: TSOC.3C (!DSR), U1.9 (DSR)
!DTR: TSOC.4C (!DTR), U1.2 (DTR)
!IRQ: TSOC.5B (!IRQ)
!JDBG: TSOC.1E (!JDBG)
!POWER: U1.14 (GPIO3)
!RI: TSOC.1C (!RI), U1.6 (RI)
!RST: TSOC.3E (!JRST), U1.19 (RESET)
!RTS: TSOC.5C (!RTS), U1.3 (RTS)
!RX_LED: U1.22 (GPIO1)
!SLEEP: U1.12 (GPIO4)
!TX_LED: U1.23 (GPIO0)
!USB1_FAULT: U3.4 (!FLAG)
BCD0: U1.28 (GPIO7)
BCD1: U1.27 (GPIO6)
BUS_DET: U1.8 (GPIO5)
GND: L2.2, TSOC.8E (GNDJ), TSOC.12B (AGND), TSOC.12C (GND), U1.7 (GND), U1.18 (GND), U1.21 (GND), U2.2 (GND), U3.2 (GND), U3.3 (!EN), USB1.GND
IO1: TSOC.2B (IO1)
IO2: TSOC.1B (IO2)
JTCK: TSOC.4E (JTCK)
JTDI: TSOC.7E (JTDI)
JTDO: TSOC.2E (JTDO)
JTMS: TSOC.5E (JTMS)
MISO: TSOC.9B (MISO)
MOSI: TSOC.10B (MOSI)
NC: U1.24 (NC), U1.25 (NC)
RXD: TSOC.7C (RXD), U1.5 (RXD)
SCK: TSOC.8B (SCK)
SCL: TSOC.9C (SCL)
SDA: TSOC.10C (SDA)
SS1: TSOC.4B (SS1)
SS2: TSOC.3B (SS2)
TXD: TSOC.8C (TXD), U1.1 (TXD)
TXDEN: U1.13 (GPIO2)
USB1_DM: U2.1 (D1A), USB1.D-
USB1_DP: U2.3 (D2A), USB1.D+
USB1_ID: USB1.ID (USBID)
USB1_M: U1.16 (USBDM), U2.6 (D1B)
USB1_P: U1.15 (USBDP), U2.4 (D2B)
USB1_SHIELD: L2.1, USB1.SHIELD1, USB1.SHIELD2
USB1_VBUS: U2.5 (VBUS), U3.1 (IN), USB1.VBUS

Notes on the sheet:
thingSoC Module Template
USB "B"
Device

Board: 2 copper layers, 6 parts (0 on the bottom side), 19 nets, no tracks yet.

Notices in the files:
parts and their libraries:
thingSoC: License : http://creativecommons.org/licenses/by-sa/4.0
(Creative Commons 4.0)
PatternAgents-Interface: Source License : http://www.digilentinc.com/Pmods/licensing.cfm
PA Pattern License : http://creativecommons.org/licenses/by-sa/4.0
